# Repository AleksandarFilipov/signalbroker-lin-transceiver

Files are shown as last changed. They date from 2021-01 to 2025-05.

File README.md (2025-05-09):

# LIN

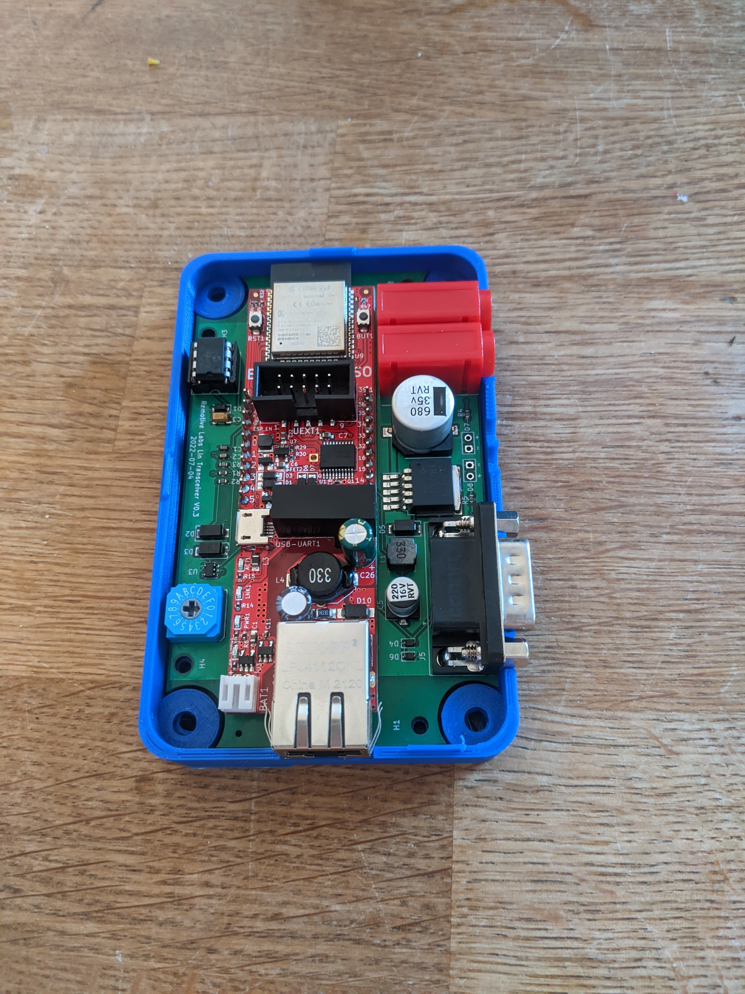
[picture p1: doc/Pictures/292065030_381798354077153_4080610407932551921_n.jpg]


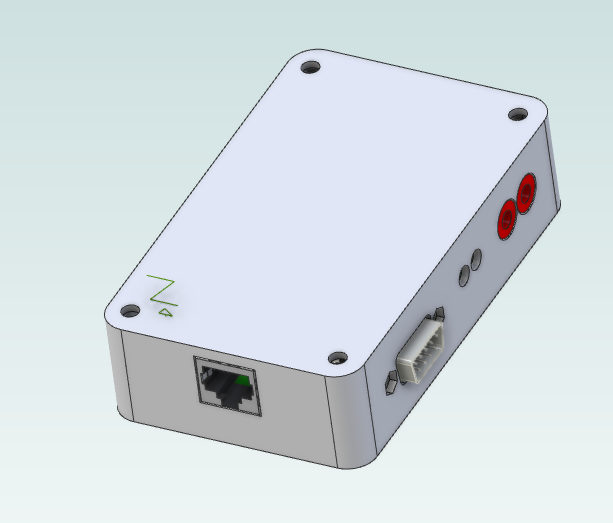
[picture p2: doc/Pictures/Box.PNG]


More images here: [link](doc/Pictures/)

## Installation 

### Prerequisites

Download USB drivers for the ESP device, choose driver depending on OS here:
https://www.olimex.com/Products/IoT/ESP32/ESP32-POE/open-source-hardware 

To be able to upload this project to your device you need PlatformIO. 
You can either install it as a [CLI application](https://docs.platformio.org/en/latest/core/index.html#) but the preferred way is to use their extension within an [IDE](https://docs.platformio.org/en/latest/integration/ide/pioide.html#).

I guess that the most popular is to use VS Code so I will use it in the example below.

#### VS Code

* [VS Code](https://code.visualstudio.com/)
* [PlatformIO Extension](https://marketplace.visualstudio.com/items?itemName=platformio.platformio-ide)

If you have installed the applications above, open this folder with VS Code.  

## Configuration

Configure the main.cpp file before uploading to the ESP32. 
### RibID - device identifier

The `rotary switch` is used to specify device identifier within the range 0..15. If you need need an id outside of the range you need to modify the source code.

>Alternatively you can hardcode, There is a `define` in the main.cpp file that holds the rib_id value for the ESP32. 

>If you have multiple ESP32 that should be connected to the same Beamy Broker, every ESP32 must have a unique rib_id.

### Master/Slave

`Master/Slave` is automatically set according to the proviced setting in `interfaces.json`

>On older PCB you need to set a jumper manually.

### DHCP

If you are intended to use DHCP the ethClient connect function should look like this
```cpp
ethClient.connect(config);
```

But if you are intended to use static IP, then the connect function should look like this instead
```cpp
ethClient.connect(config, false, IPAddress(192, 168, 1, 20), IPAddress(192, 168, 1, 10), IPAddress(255, 255, 255, 0));
```

So what does this mean? 

The false flag indicates that DHCP is disabled. 

The first IPAddress is the ESP32 address.

The second IPAdress is the host address (where the beamy broker is running)

The third IPAdress is a subnet address.

Now you are ready to upload this to your device!!

### Modify the interface.json on the server-side

When you have uploaded the firmware to your ESP32-devices and assigned them with unique rib IDs. You need to configure the interfaces.json file on the beamy broker-server side in the following way:

* namespace - Unique namespace name (you will access all necessary data from gRPC API with namespace name)
* device_identifier - rib ID that you assigned to the device
* target_host - null if using dhcp, otherwise type in IP address of esp32.
* server/target port - needs to be a unique port for each device
* node_mode: master/slave depending on how the device is connected to the LIN bus
* ldf_file - paste the link to where you have the LDF file
* schedule_file - same as ldf_file (like 99% of the times)
* schedule_table_name - type in which scheduler you want to use when you are running the device as the master
* schedule_autostart - if you are running as master and you want the provided schedule_table to autostart, this value should be true otherwise false

## Slave
If you are intended to run as a slave, your interface file should look like this (but with your settings and .ldf files). 

#### **Remember to set the right rib_id**

### DHCP

```json 
{
      "namespace": "lin_slave",
      "type": "lin",
      "config": {
        "device_identifier": 1,
        "server_port": 2014,
        "target_port": 2013
      },
      "node_mode": "slave",
      "ldf_file": "configuration/ldf_files/linone.ldf",
}
```

### Static IP

```json 
{
      "namespace": "lin_slave",
      "type": "lin",
      "config": {
        "device_identifier": 1,
        "server_port": 2014,
        "target_host": "192.168.0.20",
        "target_port": 2013
      },
      "node_mode": "slave",
      "ldf_file": "configuration/ldf_files/linone.ldf",
}
```

## Master

If you are intended to run as a master, your interface file should look like this.

### DHCP

```json 
{
      "namespace": "lin_master",
      "type": "lin",
      "config": {
        "device_identifier": 1,
        "server_port": 2014,
        "target_port": 2013
      },
      "node_mode": "master",
      "ldf_file": "configuration/ldf_files/linone.ldf",
      "schedule_file": "configuration/ldf_files/linone.ldf",
      "schedule_table_name": "linoneSchedule",
      "schedule_autostart": true
}
```

### Static IP

```json 
{
      "namespace": "lin_master",
      "type": "lin",
      "config": {
        "device_identifier": 1,
        "server_port": 2014,
        "target_host": "192.168.1.20",
        "target_port": 2013
      },
      "node_mode": "master",
      "ldf_file": "configuration/ldf_files/linone.ldf",
      "schedule_file": "configuration/ldf_files/linone.ldf",
      "schedule_table_name": "linoneSchedule",
      "schedule_autostart": true
}
```

### Debug

Logging is by default output to serial 
```
constexpr bool LOG_TO_SERIAL = true;
```
To print logs in beamy broker debug window
```
constexpr bool LOG_TO_SERIAL = false;
```

### PCB and 3D printable boxes

All ordering information of the RemotiveLIN V1.1 box along with a BOM can be found [here](/doc/Ordering%20Information)

The Box casing can be 3D printed from the [STL files](/doc/Ordering%20Information/STL%20Casing)

The PCB can be manufactured and most parts can be assempled on the PCB by www.jlcpcb.com by uploading the [gerber, BOM and pick and place files](/doc/Ordering%20Information/PCB%20V1.1%20JLCPCB%20Ordering). The parts that are not in stock at JLCPCB needs to be ordered from a seperate supplier and then handsoldered to the PCB. These part can be found in the [BOM Excel file](/doc/Ordering%20Information/Full%20BOM%20V1.1.xlsx).

#### Pinout dsub9

- 3 GND
- 7 Signal

#### Nice to know
The device does implement ping, which is helpful for debugging

>Intention is that the software supports older revision of the PCB, if that's not the case please let us know.

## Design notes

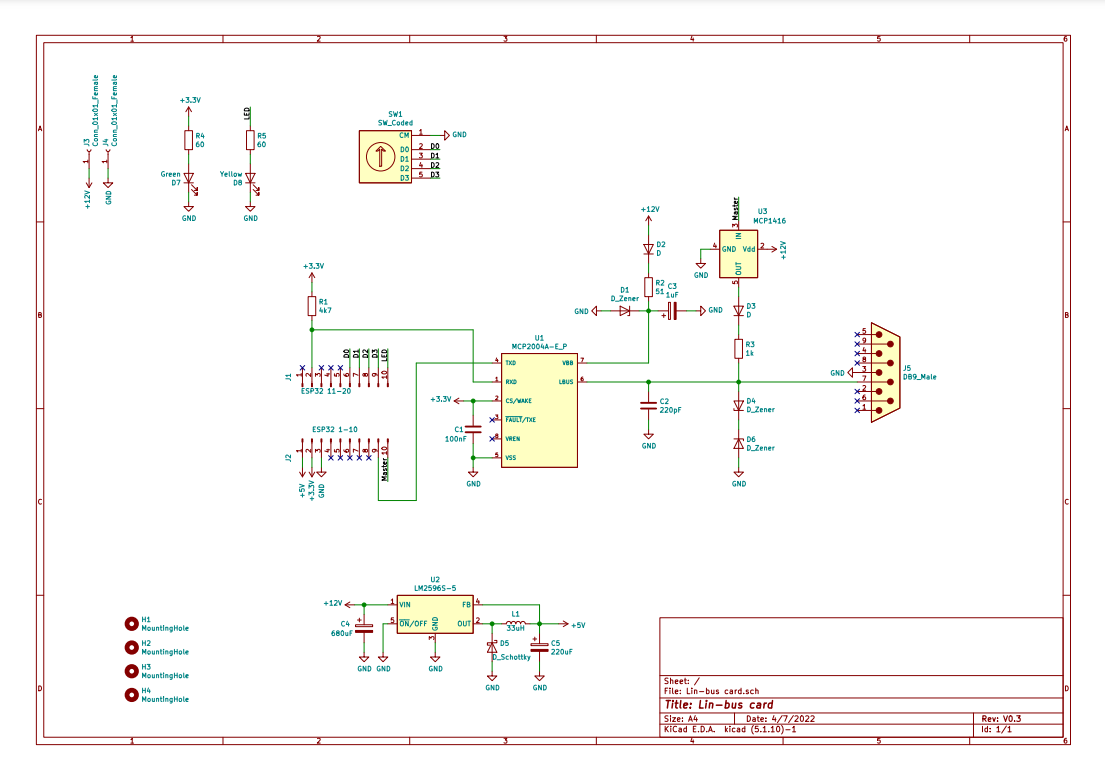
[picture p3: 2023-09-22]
doc/Pictures/Schematic.PNG

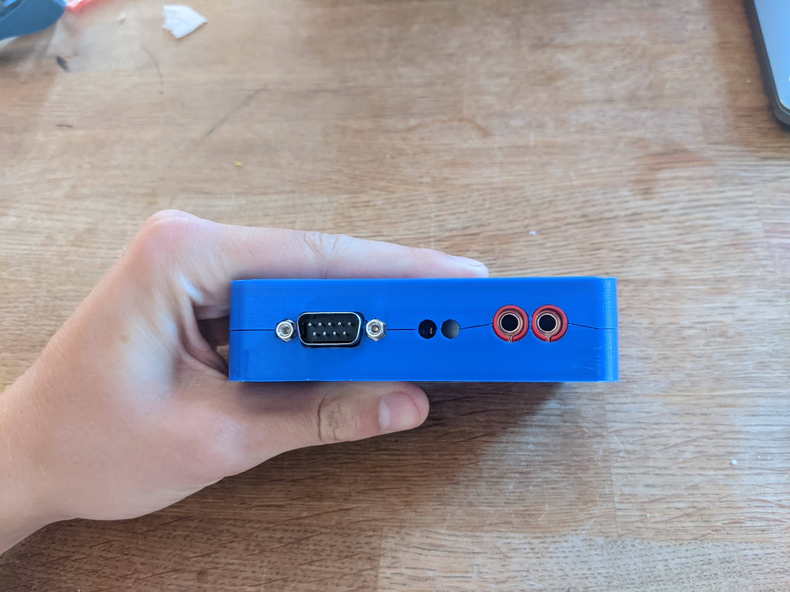
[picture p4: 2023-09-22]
doc/Pictures/292566454_431624718680918_8827222351367565866_n.jpg

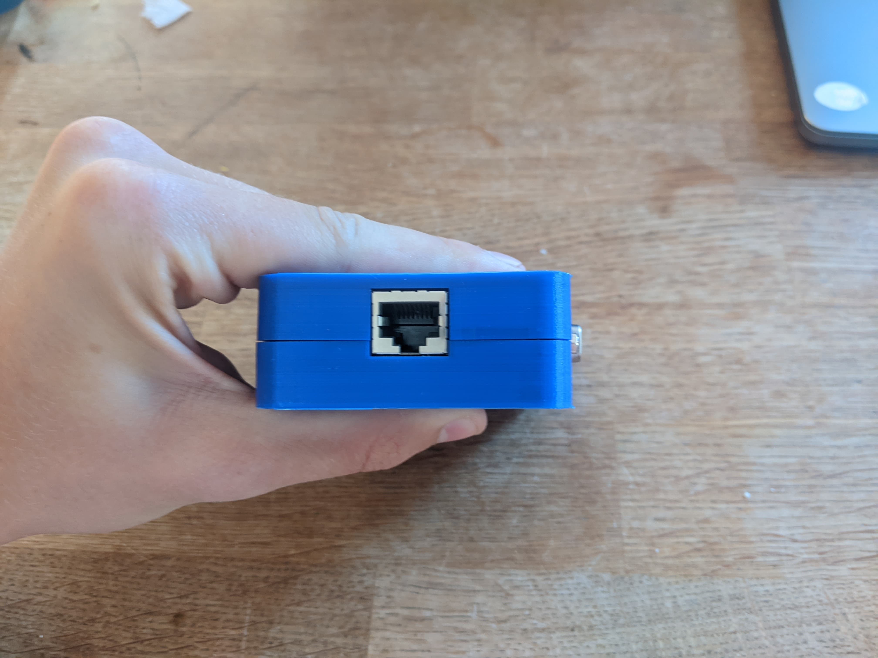
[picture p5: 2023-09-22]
doc/Pictures/293171894_1385590965279574_5704049301870776266_n.jpg

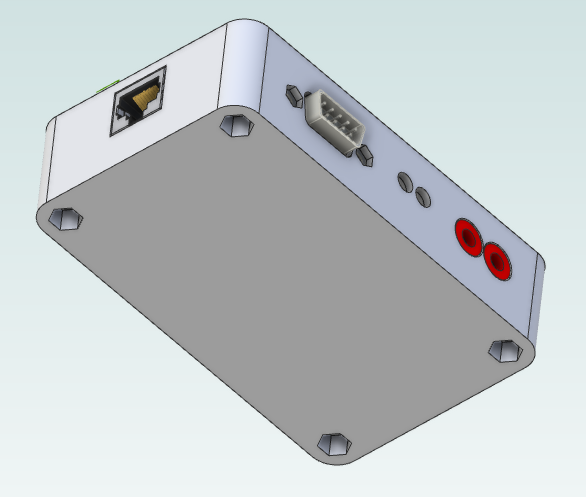
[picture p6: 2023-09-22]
doc/Pictures/Box 2.PNG

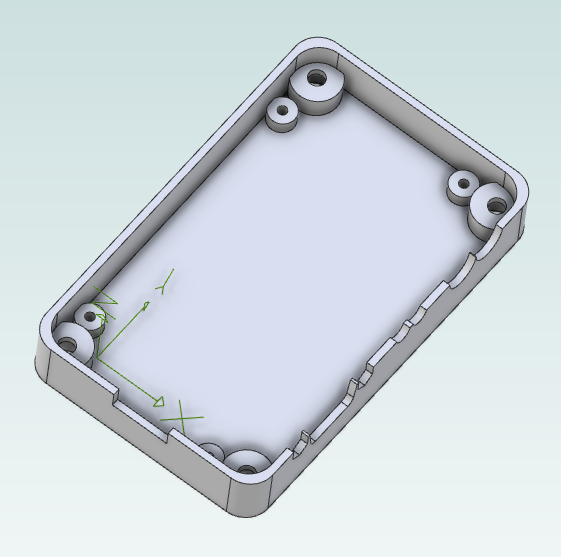
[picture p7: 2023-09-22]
doc/Pictures/Box bottom.PNG

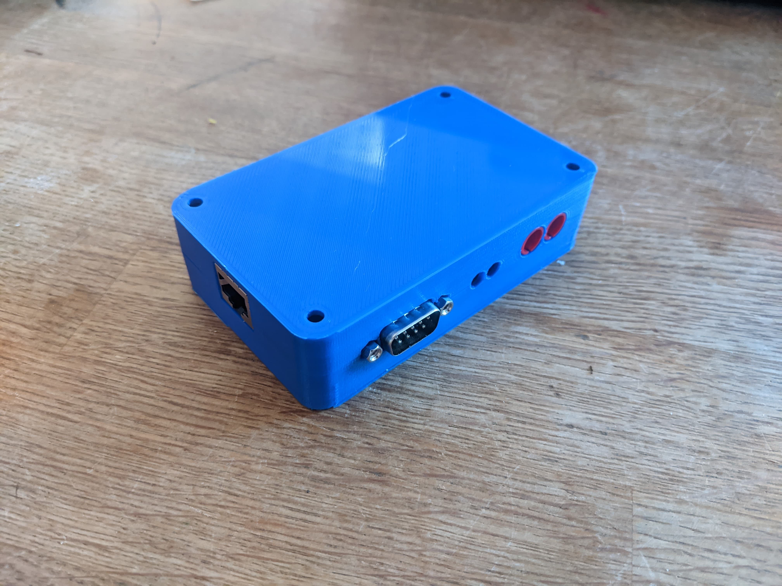
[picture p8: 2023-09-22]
doc/Pictures/292692218_8036663623017852_2703824622829600775_n.jpg

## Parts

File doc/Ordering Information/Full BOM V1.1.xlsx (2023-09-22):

Component | Manufacturer/reseller | Reseller Number | Link | Quantity per unit
Lin Tranceiver Card V1.0 | Order from jlcpcb.com |  |  | 1
Banana Contact Red | Farnell | 1698982 | https://se.farnell.com/multicomp/24-243-1/banana-socket-20a-4mm-pcb-red/dp/1698982?st=banana%20contact | 1
Banana Contact Black | Farnell | 1698983 | https://se.farnell.com/multicomp/24-243-2/receptacle-20a-4mm-pcb-solder/dp/1698983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 | 1
LED Green | Farnell | 1581138 | https://se.farnell.com/multicomp/mcl053gd/led-5mm-36-green/dp/1581138?st=green%20led | 1
Led Yellow | Farnell | 1581180 | https://se.farnell.com/multicomp/mcl053syc/led-5mm-16-yellow/dp/1581180?st=yellow+led | 1
Lin Transceiver IC | Farnell | 3385570 | https://se.farnell.com/microchip/mcp2004a-e-p/lin-transceiver-20kbaud-dip-8/dp/3385570?st=mcp2004a | 1
ESP32 Poe Iso | TME | ESP32-POE-ISO | https://www.tme.eu/se/details/esp32-poe-iso/dataoverforingssatser/olimex/ | 1
M4x25 Screw |  |  |  | 4
M4 Nut |  |  |  | 4
Box Top | 3D print from STL file |  |  | 1
Box Bottom | 3D print from STL file |  |  | 1

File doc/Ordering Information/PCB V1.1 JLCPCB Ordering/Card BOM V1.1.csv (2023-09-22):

Comment | Designator | Footprint | LCSC Part Number
100nF | C1 | 0603 | C14663
220pF | C2 | 0603 | C1603
1uF | C3 | 0603 | C141744
680uF | C4 | 12.5x13.5mm | C98216
220uF | C5 | 6.3x7.7mm | C2887273
Zener | D1 | SOD-123F | C485499
General purpose | D2,D3 | DO-214AC | C727081
Zener | D4,D6 | SOD-323 | C22621
Schottky | D5 | DO-214AC | C22452
33uH | L1 | 6.0x6.0mm | C83451
4K7 | R1 | 0603 | C269694
51 | R2 | 0603 | C23197
1K | R3 | 0603 | C14676
75 | R4,R5 | 0603 | C4275
Socket | U1 | DIP-8 | C72124
DC-DC Regulator | U2 | TO-263 | C347421
Mosfet Driver | U3 | MCP1416T-E/OT | C83775
Pin Header | J1,J2 | HDR-TH | C2894933
D-Sub | J5 | DB9-TH | C75750
Rotary encoder | SW1 | TH | C411259

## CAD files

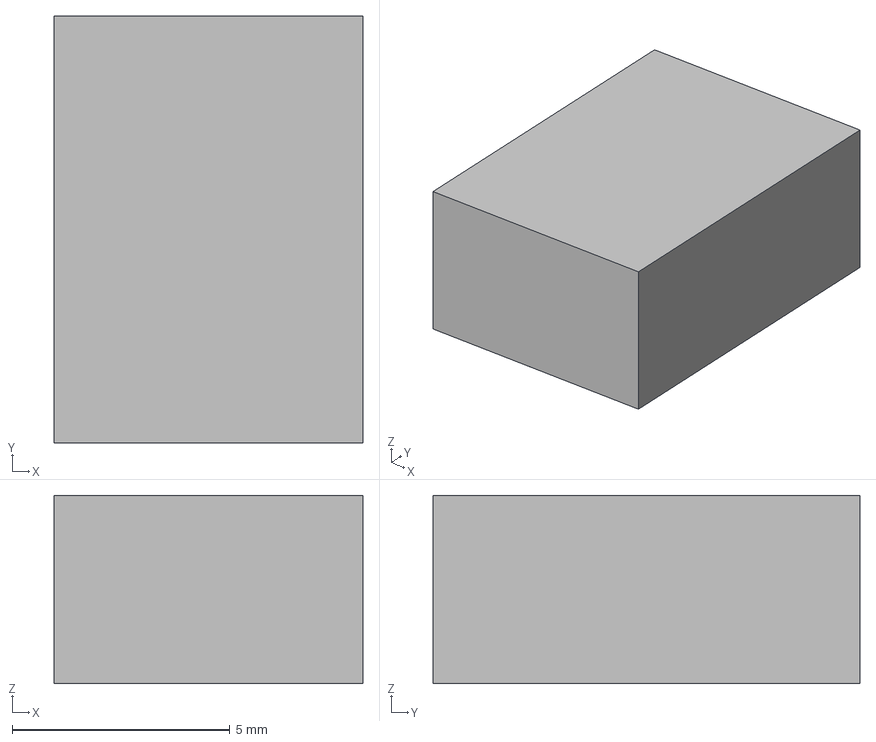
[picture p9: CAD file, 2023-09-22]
doc/Kicad parts library/IC_Microchip_MCP2004A-E_P/eec.models/Microchip_-_MCP2004A-E/P.step
7.10 x 9.80 x 4.32 mm

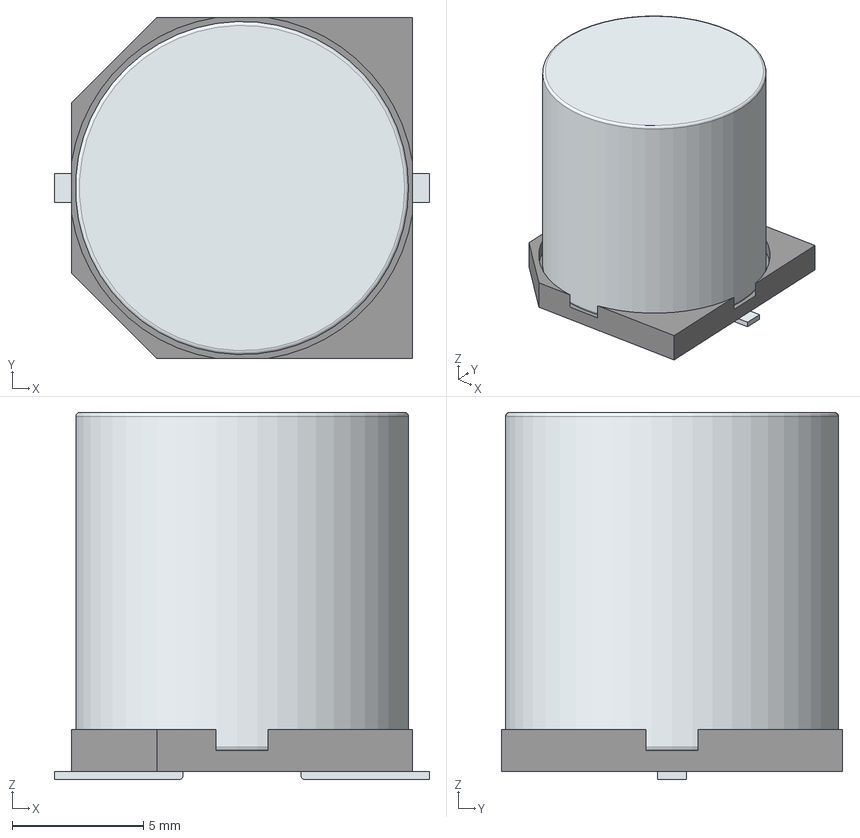
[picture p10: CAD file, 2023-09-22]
doc/Kicad parts library/LIB_50SEV330M12.5X13.5/50SEV330M12.5X13.5/3D/50SEV330M12.5X13.5.stp
14.3 x 13.0 x 14.0 mm
Base
Pin1Fillet
Pin2Fillet

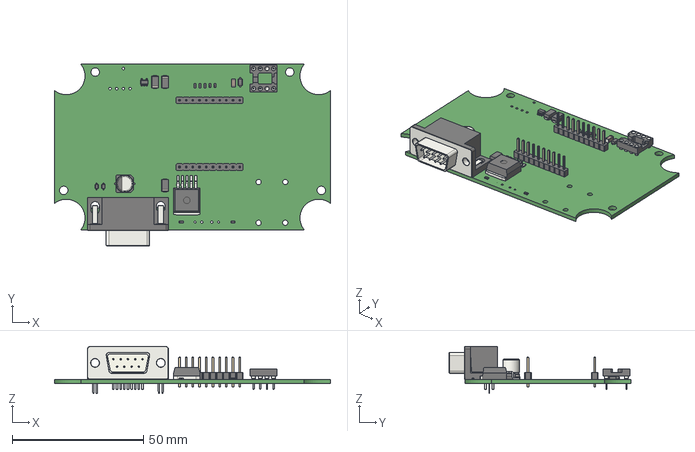
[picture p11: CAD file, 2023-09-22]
doc/Lin-bus card Kicad/Lin-bus card.step
105.0 x 69.1 x 17.9 mm

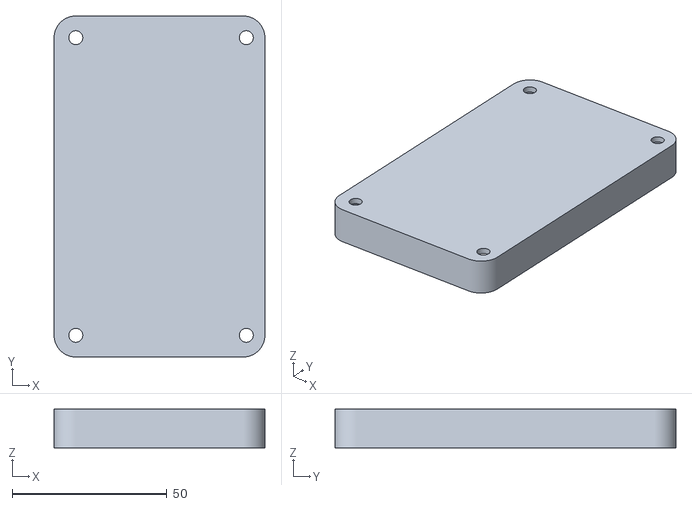
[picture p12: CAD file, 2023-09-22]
doc/Ordering Information/STL Casing/Box Top.stl
68.0 x 110.0 x 12.5

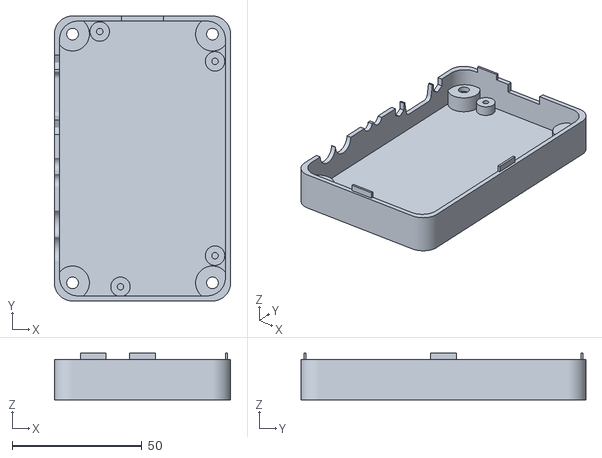
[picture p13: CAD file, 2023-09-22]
doc/Ordering Information/STL Casing/Box Bottom.stl
68.0 x 110.0 x 18.0

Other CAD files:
doc/Lin-bus card Kicad/Lin-bus card 3.step
doc/Kicad parts library/LIB_50SEV330M12.5X13.5/50SEV330M12.5X13.5/3D/50SEV330M12.5X13.5.stl
doc/Kicad parts library/LIB_50SEV330M12.5X13.5/50SEV330M12.5X13.5/Allegro/capae1275x1400n.psm
doc/Kicad parts library/LIB_50SEV330M12.5X13.5/50SEV330M12.5X13.5/DEHDL/50sev330m12.5x13.5/chips/chips.prt

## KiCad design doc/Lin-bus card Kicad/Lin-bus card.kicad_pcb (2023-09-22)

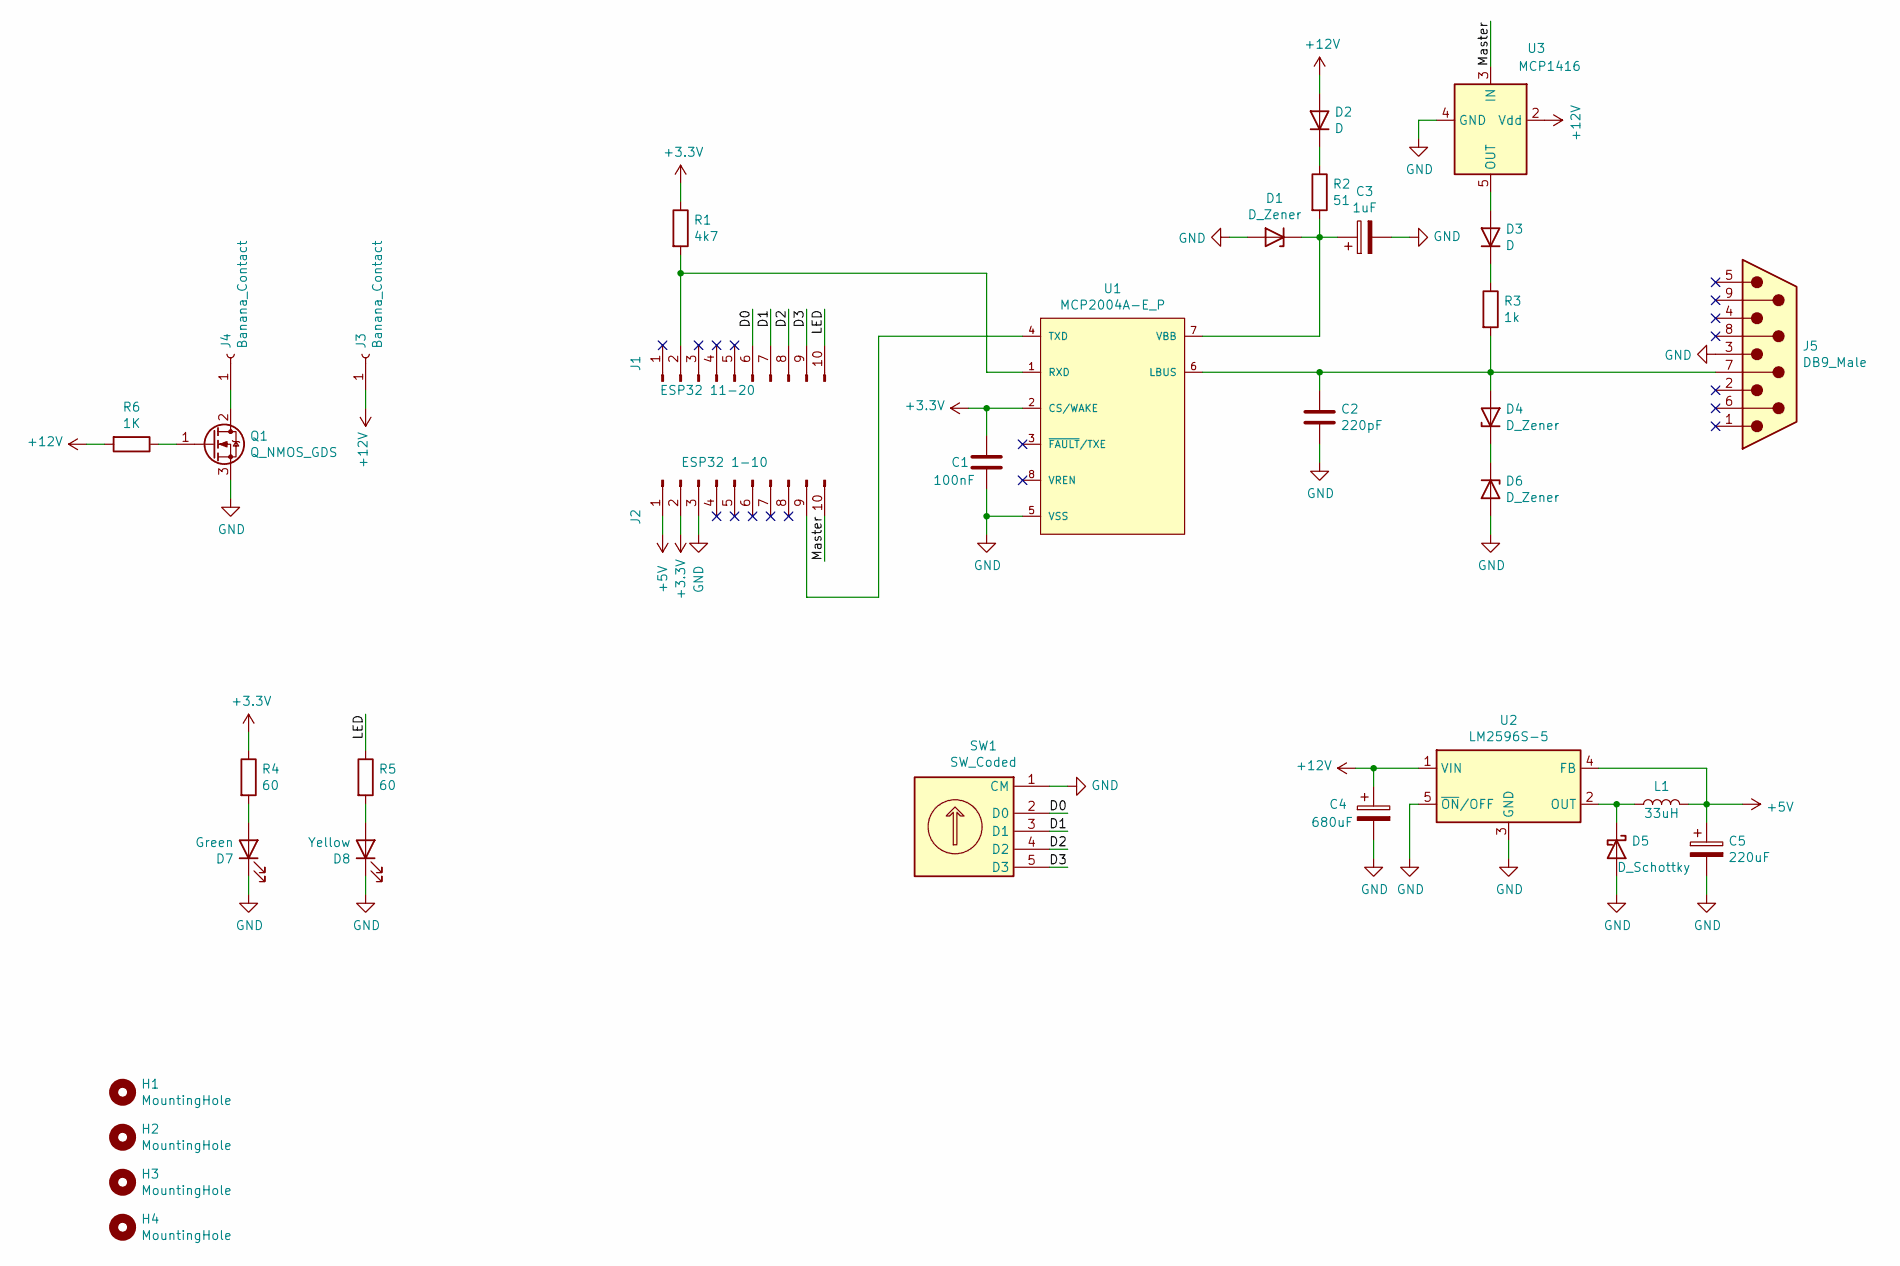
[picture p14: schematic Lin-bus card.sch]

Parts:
C1: 100nF; C_0603_1608Metric; LCSC C14663
C2: 220pF; C_0603_1608Metric; LCSC C1603
C3: 1uF; C_1206_3216Metric; LCSC C141744
C4: 680uF; 12.5x13.5cp-AS; LCSC C98216
C5: 220uF; CP_Elec_6.3x7.7; LCSC C2887273
D1: D_Zener; D_SOD-123F; LCSC C485499
D2, D3: D; D_SMA; LCSC C727081
D4, D6: D_Zener; D_SOD-323; LCSC C22621
D5: D_Schottky; D_SMA; LCSC C22452
D7: Green; Small_LED
D8: Yellow; Small_LED
H1, H2, H3, H4: MountingHole; MountingHole_3.2mm_M3
J1: ESP32 11-20; PinHeader_1x10_P2.54mm_Vertical; LCSC C2894933
J2: ESP32 1-10; PinHeader_1x10_P2.54mm_Vertical; LCSC C2894933
J3, J4: Banana_Contact; Banana_Jack
J5: DB9_Male; DSUB-9_Male_Horizontal_P2.77x2.84mm_EdgePinOffset7.70mm_Hou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; LCSC C75750
L1: 33uH; L_Wuerth_HCI-5040; LCSC C83451
Q1: Q_NMOS_GDS; TO-252-2
R1: 4k7; R_0603_1608Metric; LCSC C269694
R2: 51; R_0603_1608Metric; LCSC C23197
R3: 1k; R_0603_1608Metric; LCSC C14676
R4, R5: 60; R_0603_1608Metric
R6: 1K; R_0603_1608Metric
SW1: SW_Coded; Rotary_Encoder_AS
U1: MCP2004A-E_P; DIP-8_W7.62mm_Socket; LCSC C72124
U2: LM2596S-5; TO-263-5_TabPin3; LCSC C347421
U3: MCP1416; SOT-23-5

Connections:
+3V3: C1.1, J2.2, R1.1, R4.1, U1.2 (CS/WAKE)
+5V: C5.1, J2.1, L1.2, U2.4 (FB)
+12V: C4.1, D2.2 (A), J3.1, R6.2, U2.1 (VIN), U3.2 (Vdd)
/D0: J1.6, SW1.2 (D0)
/D1: J1.7, SW1.3 (D1)
/D2: J1.8, SW1.4 (D2)
/D3: J1.9, SW1.5 (D3)
/LED: J1.10, R5.1
/Master: J2.10, U3.3 (IN)
GND: C1.2, C2.2, C3.2, C4.2, C5.2, D1.2 (A), D5.2 (A), D6.2 (A), D7.1 (K), D8.1 (K), J2.3, J5.3, Q1.3 (S), SW1.1 (CM), U1.5 (VSS), U2.3 (GND), U2.5 (~ON~/OFF), U3.4 (GND)
unnamed: C2.1, D4.2 (A), J5.7, R3.2, U1.6 (LBUS)
unnamed: C3.1, D1.1 (K), R2.2, U1.7 (VBB)
unnamed: D2.1 (K), R2.1
unnamed: D3.1 (K), R3.1
unnamed: D3.2 (A), U3.5 (OUT)
unnamed: D4.1 (K), D6.1 (K)
unnamed: D5.1 (K), L1.1, U2.2 (OUT)
unnamed: D7.2 (A), R4.2
unnamed: D8.2 (A), R5.2
unnamed: J1.2, R1.2, U1.1 (RXD)
unnamed: J2.9, U1.4 (TXD)
unnamed: J4.1, Q1.2 (D)
unnamed: Q1.1 (G), R6.1

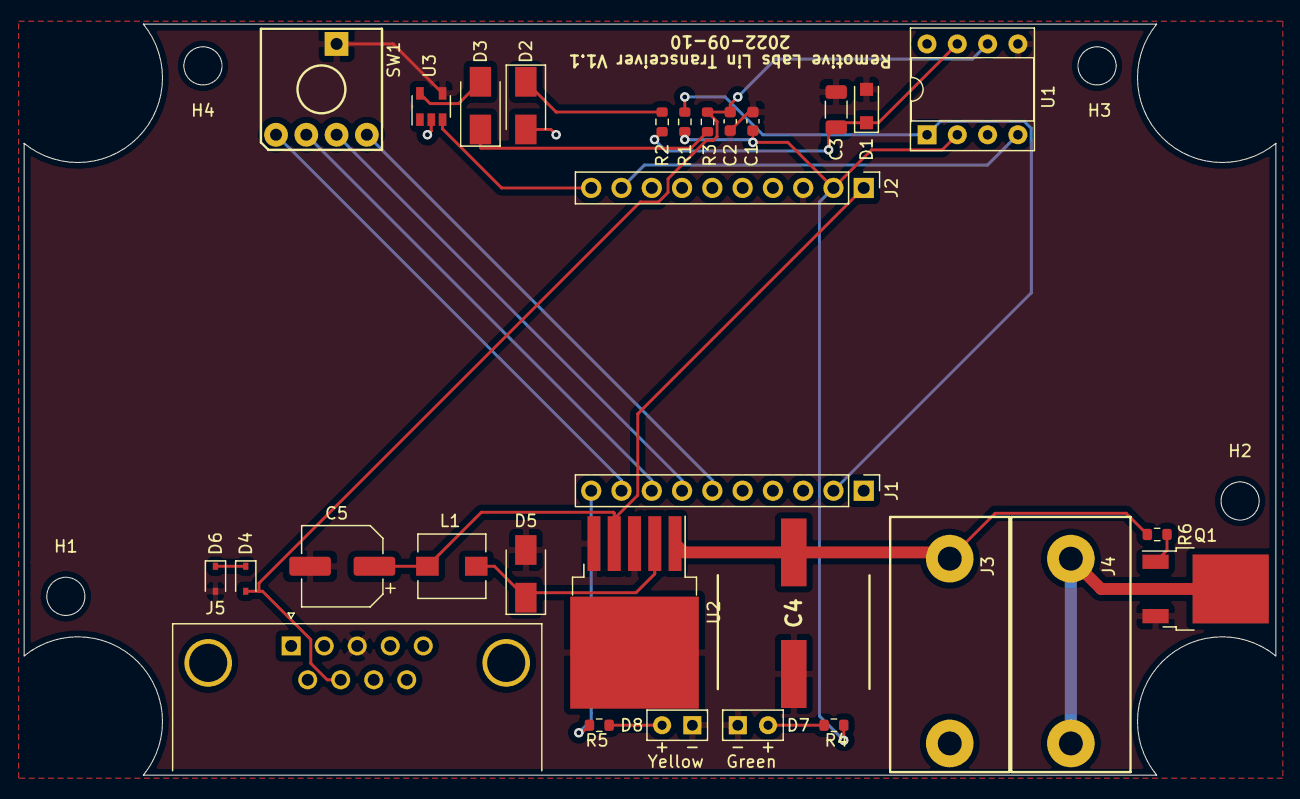
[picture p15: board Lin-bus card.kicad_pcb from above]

Board: 2 copper layers, 105.0 x 63.0 mm, 34 parts (0 on the bottom side), 23 nets.

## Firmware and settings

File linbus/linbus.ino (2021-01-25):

// Copyright 2019 Volvo Cars
//
// Licensed to the Apache Software Foundation (ASF) under one
// or more contributor license agreements.  See the NOTICE file
// distributed with this work for additional information
// regarding copyright ownership.  The ASF licenses this file
// to you under the Apache License, Version 2.0 (the
// ”License"); you may not use this file except in compliance
// with the License.  You may obtain a copy of the License at
//
//  http://www.apache.org/licenses/LICENSE-2.0
//
// Unless required by applicable law or agreed to in writing,
// software distributed under the License is distributed on an
// “AS IS" BASIS, WITHOUT WARRANTIES OR CONDITIONS OF ANY
// KIND, either express or implied.  See the License for the
// specific language governing permissions and limitations
// under the License.

//__AVR_ATmega32U4__
#ifdef ARDUINO_AVR_MICRO
//#define NIC_ENC28J60
//#define NIC_W5500
#define NIC_W5100

//#define SAVE_MEM

#elif defined ARDUINO_AVR_LEONARDO_ETH
#define NIC_W5500

#elif defined ARDUINO_AVR_FEATHER32U4
#define NIC_W5500

#else
#error "Don't know what i'm building for.."
#endif

#define DEFAULT_LIN_TIMEOUT 1000
// on lin 14, 3 is fine. 2 results in some timeout
// #define TRAFFIC_TIMEOUT 2
// #define TRAFFIC_TIMEOUT 3
#define TRAFFIC_TIMEOUT 4
#define QUERY_SIGNAL_SERVER_TIMEOUT 0
#define QUERY_CONFIG_TIMEOUT 1000


#define MAC 0x00, 0xA7, 0x0A, 0x12, 0x1B, 0x00  //00A70A is VOLVOO upside down with some good will. 12 1B is RIB (obviously..)

// dont turn this on unless you know what you are doing.

#include <HardwareSerial.h>
#include <EEPROM.h>

// https://github.com/zapta/linbus/tree/master/analyzer/arduino
// #include "lin_frame.h"
#include "lin.h"

//#include <SPI.h>         // needed for Arduino versions later than 0018

#ifdef NIC_ENC28J60
#include <UIPEthernet.h>
#include <UIPUdp.h>
#define SAVE_MEM   //The ENC28J60 lacks a TCP/IP-stack! This needs to run on the Arduino and eats a lot of memory. Beware!

#elif defined NIC_W5500
#include <Ethernet.h>
#include <EthernetUdp.h>         // UDP library from: bjoern@cs.stanford.edu 12/30/2008

#elif defined NIC_W5100
#include <Ethernet.h>
#include <EthernetUdp.h>
#endif


#define USE_DHCP true
//If DHCP is NOT used the RIB will take as its IP the ip_base + its ribID.
IPAddress ip_base = {192,168,5,50};
//Until the server adress is known we broadcast on the entire subnet
IPAddress ipserver = {255,255,255,255};


// this is used by the master to send lin BREAK
#define BREAK 0x00
#define SYN_FIELD 0x55
#define RED_PIN 7
#define GREEN_PIN 8
#define BLUE_PIN 9

byte mac[] = {
  MAC
};

#ifndef SAVE_MEM
//#define debugPrintln(...) Udp.beginPacket(ipserver, debugPort); Udp.print("["); Udp.print(mac[5]); Udp.print("]"); Udp.println(__VA_ARGS__); Udp.endPacket();
char printBuffer[80];
#define debugPrintln(...) { snprintf(printBuffer, sizeof(printBuffer), __VA_ARGS__); config.send_logg_to_server(printBuffer); Serial.print(printBuffer); Serial.print("\r\n"); }
#else
#define debugPrintln(...)
#endif

#define UNUSED(expr) { do { (void)(expr); } while (0); }

void(* SWReset) (void) = 0; //declare reset function @ address 0

union DoubleByte
{
    uint16_t u16;
    struct U8 {
      uint8_t low;
      uint8_t high;
    } u8;
};

struct Config {
  #define CONFIG_PORT 4000
  #define CONFIG_PORT_RECEIVE 4001
  #define DEBUG_PORT_BASE 3000
  #define HEARTBEAT_PERIOD 3000 //ms

  // mini protocol....
  // payload might be empty if payload_size is 0
  //   header::8, rib_id::8, hash::16 identifier::8, payload_size::16, payload::payload_size*bytes

  #define HEADER 0x04

  #define HOST_PORT (1<<0)      //1
  #define CLIENT_PORT (1<<1)    //2
  #define MESSAGE_SIZES (1<<2)  //4
  #define NODE_MODE (1<<3)      //8
    #define MODE_MASTER 1
    #define MODE_SLAVE 0
    #define MODE_NONE 0xFF
  #define REASSIGN_RIBID (1<<5) //32
  #define HEART_BEAT (1<<4)
    #define HEART_BEAT_TX_LIN (1)
    #define HEART_BEAT_RX_LIN (2)
    #define HEART_BEAT_TX_UDP (3)
    #define HEART_BEAT_RX_UDP (4)
    #define HEART_BEAT_SYNC_COUNT (5)
    #define HEART_BEAT_UNSYNCHED_PACKAGES (6)
    #define HEART_BEAT_SYNCHED_PACKAGES (7)

  #define LOGGER 0x60                  //96

  #define HEADER_OFFSET 0
  #define RIB_ID_OFFSET 1
  #define HASH_HIGH_OFFSET 2
  #define HASH_LOW_OFFSET 3
  #define IDENTIFIER_OFFSET 4
  #define PAYLOAD_SIZE_HIGH_OFFSET 5
  #define PAYLOAD_SIZE_LOW_OFFSET 6
  #define PAYLOAD_START_OFFSET 7

  void Init() {
//    ribID = getRibID();
    ribID = 1;
    mac[5] = ribID;

    lastHash.u16 = 0xFFFF;
    clientPortHash.u16 = 0;
    hostPortHash.u16 = 0;
    nodeModeHash.u16 = 0;
    messageSizesHash.u16 = 0;

    lastHeartbeat = 0;
  }

  void send_heartbeat();
  void parse_server_message();
  void verify_config();
  void request_config_item(byte item);
#ifndef SAVE_MEM
  void send_logg_to_server(const char* message);
#else
#define send_logg_to_server(X)
#endif
  uint8_t getRibID();

  uint8_t ribID; //This is calculated locally and part of the message header

  uint16_t hostPort;
  DoubleByte hostPortHash;
  uint16_t clientPort;
  DoubleByte clientPortHash;
  //size_t messageSizes;
  DoubleByte messageSizesHash;
  // "MODE_MASTER means that you need to reply to all ids, all except the master ids. For master id the data should be sent back.
  // "MODE_SLAVE" means that we send arbitration frames and master frames. Other responses should be sent back.
  uint8_t nodeMode;
  DoubleByte nodeModeHash;

  DoubleByte lastHash;  //Last server message had this config version (or config hash) and all config fields should match.
  unsigned long lastHeartbeat;
} config;

#define MAX_RECORD_ENTRIES 20
struct Record
{
    byte id;
    byte size;
    byte master;
    byte write_cache[8];
    boolean cache_valid;
} record_list[MAX_RECORD_ENTRIES];

int record_entries;

unsigned int debugPort = DEBUG_PORT_BASE;

// buffers for receiving and sending data
#define UDP_TX_PACKET_MAX_SIZE_CUSTOM 128
byte packetBuffer[UDP_TX_PACKET_MAX_SIZE_CUSTOM];  //buffer to hold incoming packet,

// An EthernetUDP instance to let us send and receive packets over UDP
EthernetUDP Udp;
EthernetUDP UdpConfig;
EthernetUDP UdpConfigReceive;

// byte b, i, n, b2;
// LinFrame frame;
Lin lin(SERIAL_PORT_HARDWARE);

void Abort() {
  pinMode(LED_BUILTIN, OUTPUT);
  for (int i=0; i<10; ++i) {
    digitalWrite(LED_BUILTIN, HIGH);
    delay(100);
    digitalWrite(LED_BUILTIN, LOW);
    delay(100);
  }
  SWReset();
}

int TxOverLin = 0;
int RxOverLin = 0;
int TxOverUdp = 0;
int RxOverUdp = 0;
int global_sync_count = 0;
int global_unsynched_packages = 0;
int global_synched_packages = 0;

void setup() {
  Serial.begin(19200);
  config.Init();

  // configure ethernet
  if (!USE_DHCP || !Ethernet.begin(mac)) { //try DHCP, but if it doesn't work, use a static IP
     ip_base[3] += config.ribID;
     Ethernet.begin(mac, ip_base); //Static IP
  }

  pinMode(LED_BUILTIN, OUTPUT);
  pinMode(RED_PIN, OUTPUT);
  pinMode(GREEN_PIN, OUTPUT);
  pinMode(BLUE_PIN, OUTPUT);

  UdpConfig.begin(CONFIG_PORT);
  UdpConfigReceive.begin(CONFIG_PORT_RECEIVE);

  debugPrintln("LIN Debugging begins");
  lin.begin(19200);
  lin.serial.setTimeout(DEFAULT_LIN_TIMEOUT);
}

void led_status_ok() {
  digitalWrite(LED_BUILTIN, HIGH);

  // external led
  digitalWrite(GREEN_PIN, LOW);
  digitalWrite(RED_PIN, LOW);
  digitalWrite(BLUE_PIN, LOW);
  if (MODE_MASTER == config.nodeMode) {
    digitalWrite(GREEN_PIN, HIGH);
  } else if (MODE_SLAVE == config.nodeMode){
    digitalWrite(BLUE_PIN, HIGH);
  }
}

void red() {
  digitalWrite(LED_BUILTIN, LOW);

  // external led
  digitalWrite(GREEN_PIN, LOW);
  digitalWrite(RED_PIN, LOW);
  digitalWrite(RED_PIN, HIGH);
  digitalWrite(BLUE_PIN, LOW);
}

void flush_udp_buffer(EthernetUDP* flushUdp) {
  int packetSize = 0;
  do {
    packetSize = flushUdp->parsePacket();
  } while (packetSize != 0);
}

// psudo code for simulating slave. Master sends arbritration messages.
// we respond appropriate. This means that slaves must be disconnected
// to avoid bus craziness.
// example frames..
//  3    D0 8 C0 B  6  0  8 BC   8D
// 47    BB F BB F 80 BB 6F   77 (where 77 is checksum and 47 is id)

#ifndef NO_LIN
Record* getRecord(byte id) {
  Record* record = NULL;
  for (int i = 0; i< record_entries; i++) {
    if (record_list[i].id == id) {
      record = &record_list[i];
      break;
    }
  }
  return record;
}

byte readbuffer[10];

void readLinAndSendOnUdp(byte id) {
  // readbuffer   0  1  2        3        4       10
  //              id payload1 payload2...         crc
  // count        0        1        2
  boolean crc_valid = false;
  byte payload_size = 0;


  lin.serial.setTimeout(TRAFFIC_TIMEOUT);
  readbuffer[0] = (byte)(lin.addrParity(id) | id);

  Record* record = getRecord(id);
  if (record != NULL) {
    int verify = 0;
    payload_size = record->size;
    // adding one for crc.
    verify = lin.serial.readBytes(&readbuffer[1], payload_size + 1);
    if (verify == (payload_size + 1)) {
      if ((id == 60) || (id == 61)) {
        // calculate checksum in traditional way for diagnstic frames.
        crc_valid = lin.validateChecksum(&readbuffer[1], payload_size+1);
      } else {
        crc_valid = lin.validateChecksum(&readbuffer[0], payload_size+2);
      }
      RxOverLin++;
    } else {
      // debugPrintln("timeout8 length missmatch");
      // debugPrintln(payload_size + 1);
    }
  } else {
    red();
    //debugPrintln("invalid id: 0x%x (%d)", id, id);
  }
  // return to default timeout.
  lin.serial.setTimeout(DEFAULT_LIN_TIMEOUT);

  if (crc_valid) {
    led_status_ok();
#ifdef VERBOSE_DBG
    debugPrintln("++crc match for id: 0x%x  length is: %d", id, payload_size);
    for(int i = 0; i < payload_size+1; i++)
    {
      debugPrintln("0x%x", readbuffer[i]);
    }
#endif
    sendOverUdp(id, &readbuffer[1], payload_size);
  } else {
    // red();
#ifdef VERBOSE_DBG
    debugPrintln("--crc failed for id: 0x%x  count is: %d", id, payload_size);
#endif
  }
}

byte toServerPayload[] = {
  0x00, 0x00, 0x00, 0x00, 0x00, 0x00, 0x00, 0x00, 0x00, 0x00, 0x00, 0x00, 0x00
};

void sendOverUdp(byte id, byte* payload, byte size) {
  byte* payloadLocal = &toServerPayload[5];
  toServerPayload[3] = id;
  toServerPayload[4] = size;
  for (int i = 0; i < size; i++) {
    payloadLocal[i] = payload[i];
  }
  if (!Udp.beginPacket(ipserver, config.hostPort)) {
    debugPrintln("!!! Failed to open UDP socket: %d, %d, %d, %d: %d for send", ipserver[0], ipserver[1], ipserver[2], ipserver[3], config.hostPort);
  } else {
    Udp.write(toServerPayload, 5+size);
    Udp.endPacket();
    TxOverUdp++;
    //debugPrintln("Sending %d bytes on port %d", size, config.hostPort);
  }
}

// for testing on lin18 frame 0x09
byte hardcoded[] = {
0x01, 0x02, 0x03,
  0x04, 0x2b
};

byte sendbuffer[10];
void sendOverSerial(Record* record) {
  byte id = record->id;
  sendbuffer[0] = lin.addrParity(id) | id;
  byte* sendbuffer_payload = &sendbuffer[1];
  for (int i = 0; i < record->size; i++) {
    sendbuffer_payload[i] = record->write_cache[i];
  }
  byte* crc = &sendbuffer[1+record->size];
  if ((id == 60) || (id == 61)) {
    // calculate checksum in traditional way for diagnstic frames.
    crc[0] = (byte)lin.calulateChecksum(&sendbuffer[1], record->size);
  } else {
    crc[0] = (byte)lin.calulateChecksum(sendbuffer, record->size + 1);
  }
  //this code fixes consequent synch isseus.
  lin.serial.write(&sendbuffer[1], record->size + 1);
  lin.serial.flush();
  lin.serial.end();
  TxOverLin++;
  lin.serial.begin(19200);
}

// byte hardcoded[] = {
//   0x0, 0x0, 0x0, 0x10, 0x08, 0x01, 0x02, 0x03, 0x04, 0x05, 0x06, 0x07, 0x08
// };

// {"command":"write","signals":{"CmptmRelHum":27.0, "CmptmtRelHumQf":2,"SnsrStsForBattU":3, "SnsrStsForRelHum":4, "SnsrStsForWindT":5,"SnsrStsForWindTRef":6, "WindDewT":7,"WindDewTQf":8, "WindT":9, "WindTQf":10, "WindTRef":42.5, "WindTRefQf":12, "ErrRespHUS":13}, "namespace" :"Lin"}
// byte hardcoded[] = {
//    0x0, 0x0, 0x0, 0x10, 0x08, 129, 214, 2, 28, 75, 57, 193, 234
// };

byte consumeUdpMessage(byte* buffer, int temp_timeout) {
  int packetSize = 0;
  int bytes = 0;
  unsigned long endtime = millis() + temp_timeout;
  do {
    packetSize = Udp.parsePacket();
    if (packetSize) {
      Udp.setTimeout(temp_timeout);
      bytes = Udp.read(buffer, UDP_TX_PACKET_MAX_SIZE_CUSTOM);
      Udp.setTimeout(DEFAULT_LIN_TIMEOUT);
      // debugPrintln("Read %d on port %d", bytes, config.clientPort);
      RxOverUdp++;
    }
  } while ((packetSize == 0) && (millis() < endtime));
  return bytes;
}


void cacheUdpMessage(Record* record, byte id) {
  int bytes;
  do {
    bytes = consumeUdpMessage(packetBuffer, QUERY_SIGNAL_SERVER_TIMEOUT);
    // fake packetbuffer
    // int bytes = 13;
    // for (int i = 0; i < 13; i++) {
    //   packetBuffer[i] = hardcoded[i];
    // }
    // id plus size shold aways be at least 5 bytes.
    if (bytes >= 4) {
      Record* updateRecord = record;
      if (packetBuffer[3] != id) {
        updateRecord = getRecord(packetBuffer[3]);
        // debugPrintln("missmatch udp responce");
      }
      if (updateRecord == NULL) {
        debugPrintln("missmatch id does not exist");
      } else {
        memcpy(updateRecord->write_cache, &packetBuffer[5], updateRecord->size);
        updateRecord->cache_valid = true;
      }
    } else {
      if ((bytes < 4) && (bytes != 0)) {
        debugPrintln("signalserver payload to short");
        red();
      }
    }
  } while (bytes != 0);
}

void measureSignalBrokerBouce() {
  for (;;) {
    // debugPrintln("staring");
    unsigned long t = micros();
    byte empty = 0;
    sendOverUdp(0x24, &empty, 0);
    int packetSize;
    int bytes;
    UNUSED(bytes);

    //wait for signalserver to respond
    do {
      packetSize = Udp.parsePacket();
      if (packetSize) {
        bytes = Udp.read(packetBuffer, UDP_TX_PACKET_MAX_SIZE_CUSTOM);
      }
    } while (packetSize == 0);
    // debugPrintln("done micros passed: ");
    debugPrintln("measureSignalBrokerBouce: %d", (micros() - t));
    // debugPrintln(" bytes: ");
    // debugPrintln(bytes);
  }
}
#endif //NO_LIN

uint8_t Config::getRibID() {
  //address @0000-@0001 = 0x131B if an ID has been stored in EEPROM
  if (0x13 == EEPROM.read(0) && 0x1B == EEPROM.read(1)) {
    return EEPROM.read(2); //next byte is the RibID
  }

  // Read jumper configuration
  // Pull any combination of pins 2,3 and 4 to LOW to set a RIB ID
  // Pins will initially have random values unless pulled to HIGH or LOW.
  // First pull the config pins to HIGH from SW and then check what pins have been pulled LOW by bridging to GND.
  int jumperCfg = 1; //one-based index
  const int firstCfgPin = 2;
  const int lastCfgPin = 4;
  for (int pin=firstCfgPin; pin<=lastCfgPin; ++pin) {
    pinMode(pin, OUTPUT);
    digitalWrite(pin,HIGH);
    pinMode(pin, INPUT);
    if (LOW == digitalRead(pin)) {
      jumperCfg += 1 << (pin-firstCfgPin);
    }
  }
  return jumperCfg;
}

void Config::send_heartbeat() {

  if (millis() > lastHeartbeat + HEARTBEAT_PERIOD) {
    //flush_udp_buffer(&UdpConfig);
    debugPrintln("Sending heartbeat with hash 0x%x", lastHash.u16);
    UdpConfig.beginPacket(ipserver, CONFIG_PORT);
    UdpConfig.write(HEADER);
    UdpConfig.write(ribID);
    UdpConfig.write(lastHash.u8.high);
    UdpConfig.write(lastHash.u8.low);
    UdpConfig.write(HEART_BEAT);

    //payload size
    UdpConfig.write((byte)0x00);
    UdpConfig.write((byte)21);

    DoubleByte local;

    local.u16 = RxOverLin;
    UdpConfig.write((byte)HEART_BEAT_RX_LIN);
    UdpConfig.write(local.u8.high);
    UdpConfig.write(local.u8.low);

    local.u16 = TxOverLin;
    UdpConfig.write((byte)HEART_BEAT_TX_LIN);
    UdpConfig.write(local.u8.high);
    UdpConfig.write(local.u8.low);

    local.u16 = RxOverUdp;
    UdpConfig.write((byte)HEART_BEAT_RX_UDP);
    UdpConfig.write(local.u8.high);
    UdpConfig.write(local.u8.low);

    local.u16 = TxOverUdp;
    UdpConfig.write((byte)HEART_BEAT_TX_UDP);
    UdpConfig.write(local.u8.high);
    UdpConfig.write(local.u8.low);

//sync
    local.u16 = global_sync_count;
    UdpConfig.write((byte)HEART_BEAT_SYNC_COUNT);
    UdpConfig.write(local.u8.high);
    UdpConfig.write(local.u8.low);

    local.u16 = global_unsynched_packages;
    UdpConfig.write((byte)HEART_BEAT_UNSYNCHED_PACKAGES);
    UdpConfig.write(local.u8.high);
    UdpConfig.write(local.u8.low);

    local.u16 = global_synched_packages;
    UdpConfig.write((byte)HEART_BEAT_SYNCHED_PACKAGES);
    UdpConfig.write(local.u8.high);
    UdpConfig.write(local.u8.low);

//end


    UdpConfig.endPacket();

    lastHeartbeat = millis();

    // debugPrintln("RxOverLin: %d, TxOverLin: %d, RxOverUdp: %d, TxOverUdp: %d",
    //   RxOverLin,TxOverLin,RxOverUdp,TxOverUdp);
    RxOverLin=TxOverLin=RxOverUdp=TxOverUdp=0;
    global_sync_count=global_unsynched_packages=global_synched_packages=0;

  }
}

void Config::request_config_item(byte item) {

  //flush_udp_buffer(&UdpConfig);
  debugPrintln("Rerequesting config item 0x%x", item);
  UdpConfig.beginPacket(ipserver, CONFIG_PORT);
  UdpConfig.write(HEADER);
  UdpConfig.write(ribID);
  UdpConfig.write(lastHash.u8.high);
  UdpConfig.write(lastHash.u8.low);
  UdpConfig.write(item);
  UdpConfig.write((byte)0x00);
  UdpConfig.write((byte)0x00);
  UdpConfig.endPacket();
}
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
void loop() {

/// RIB configuration
  config.send_heartbeat();
  config.parse_server_message();
  config.verify_config();

  led_status_ok();
  // measureSignalBrokerBouce();

  //flush_udp_buffer(&Udp);
  //debugPrintln("udp buffers empty");

/// Actual LIN traffic
#ifndef NO_LIN
  // debugPrintln("Softserial test (this is real serial)");
  if (MODE_MASTER == config.nodeMode) {
    // wait for server/automatic or manually to write arbitration frame
    int bytes = 0;
    bytes = consumeUdpMessage(packetBuffer, QUERY_SIGNAL_SERVER_TIMEOUT);
    if (bytes >= 5) {
      byte id = packetBuffer[3];
      Record* record = getRecord(id);
      boolean validpayload = ((bytes == 5) || (bytes == (5 + record->size)));
      if (validpayload) {
        if (bytes == 5) {
          //this is an arbiration frame
          if (!record->master) {
            writeHeader(id);
            // now consume the result
            readLinAndSendOnUdp(id);
          } else {
            // ignore this - a full frame will arrive on upd. Once it does we write it (length > 5)
          }
        } else {
          // this a master frame. Send it all..
          writeHeader(id);
          memcpy(record->write_cache, &packetBuffer[5], record->size);
          sendOverSerial(record);
        }
      } else {
        debugPrintln("incorrect data received over udp id: 0x%x bytes: 0x%x", id, bytes);
      }
    }
  } else if(MODE_SLAVE == config.nodeMode) {
    if (lin.serial.available()) {
      //find startposition look for BREAK followed BY SYN_FIELD
      // we expect this to be the header if it's not read bytes until conditions are met.
      byte id;
      //we now should have BREAK, SYN_FIELD followed by ID.
      //Now check parity
      //remove parity bits and then add them again. Check if it mathes whats expected
      byte empty = 0;
      byte idbyte = synchHeader();
      id = idbyte & 0x3f;
      if ((lin.addrParity(id) | id) == idbyte) {
        // send this arbitration frame to the server.
        Record *record = getRecord(id);
        // debugPrintln("processing id: ");
        // debugPrintln(id);
        // this works!!
        // if ((id != 0x10) || record->master) {
        if (record->master || (!record->cache_valid)) {
        // if (true) {
        // if (record != NULL && ((boolean)record->master)) {
          // the master is sending data, just consume and report back.
          sendOverUdp(id, &empty, 0);
          // if (record->master) {
            readLinAndSendOnUdp(id);
          // }
        } else {
          // signalserver should response with the expected payload
          if (record->cache_valid) {
            sendOverSerial(record);
            // this is intetionally after writing to serial which might be counterintuitive,
            // in order to meet timing req for short messages
            sendOverUdp(id, &empty, 0);
          }
          // else {
          //   debugPrintln("messed up");
          //   debugPrintln(id);
          // }
        }
        cacheUdpMessage(record, id);
      } else {
        debugPrintln("parity failure - do nothing (id %d)", id);
      }
    }
  } else {
    //We are neither Master nor Slave. ie. unconfigured.
  }

#ifdef VERBOSE_DBG
  debugPrintln("no serial activity");
#endif
#endif NO_LIN
}

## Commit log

2021-10-18 Create esp32-build.yml
    Add CI for push and PR's.
2022-08-17 added antons updated pcb
    [12V power card-B_Cu.gbl, 12V power card-B_Mask.gbs, 12V power card-B_SilkS.gbo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]
2022-08-17 added STLs for casing
    [Box Top 2022-11-07.stl, Box bottom 2022-11-07.stl]
2022-08-17 fixed value on resistor
    [BOM V0.3.csv]
2022-08-17 use led to flash when traffic arrives or is sent
2022-08-17 allow manual rib id selection in order to stay compaible with older pcb:s
2022-11-10 RemotiveLIN V1.1 with new reverse polarity protection mosfet. Updated README file with new ordering information for the box. Updated dimensions in the STL file for 3D printing of the box.
    [BOM V0.2.csv, BOM V0.2.xlsx, BOM V0.3.csv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]
2022-11-18 Ordering information of the PCB and casing added to README
2024-09-02 add ability to change configuration port device -> server
